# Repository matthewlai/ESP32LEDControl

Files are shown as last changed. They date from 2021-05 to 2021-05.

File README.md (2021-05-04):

# ESP32LEDControl

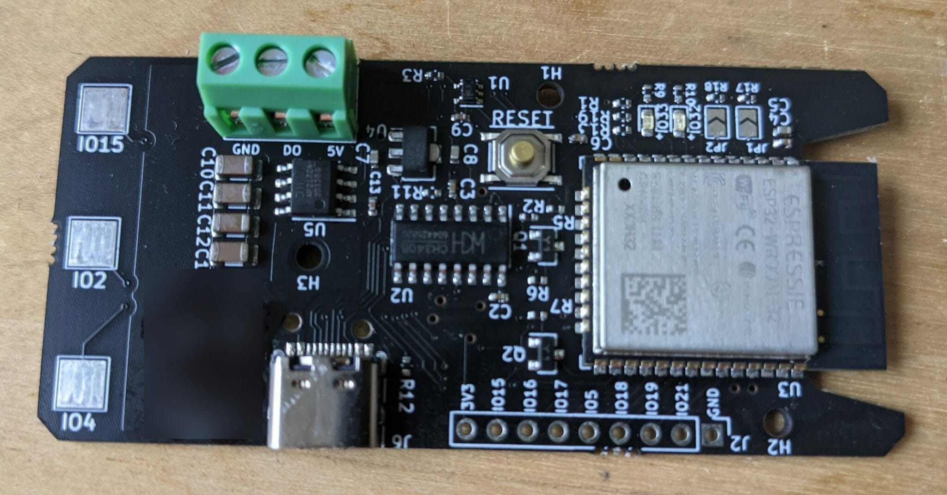
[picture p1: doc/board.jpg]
PCB photo


ESP32-based LED controller for WS2812B-compatible LEDs, powered by USB Type-C.

This is the hardware component of Fede Heinz's [Blinkenlights project](https://github.com/fheinz/Blinkenlights).

See [this blog post](https://dubiouscreations.com/2021/05/04/designing-an-esp32-based-rgb-matrix-driver-and-making-500-of-them/) for more details.

This hardware design is licensed under Attribution-ShareAlike 4.0 International (CC BY-SA 4.0) as published by the Creative Commons. You can find a copy of the license [here](https://creativecommons.org/licenses/by-sa/4.0/).

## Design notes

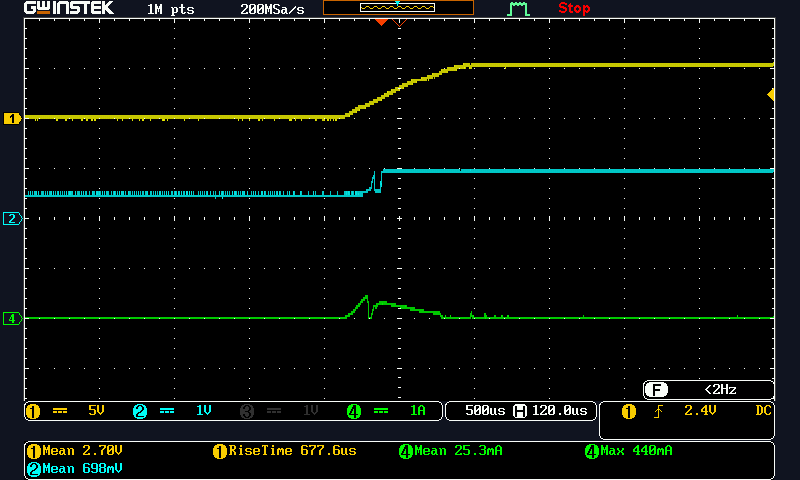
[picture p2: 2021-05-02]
hardware/esp32_led_controller/doc/rev4_hw_qual/plug_in.png

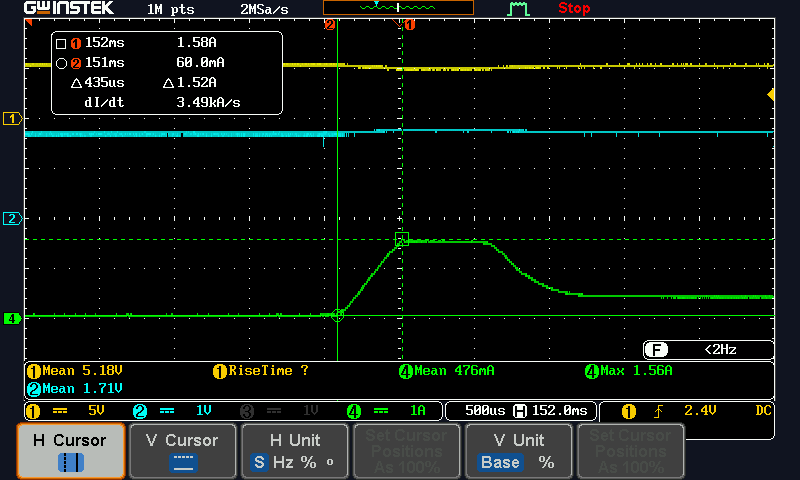
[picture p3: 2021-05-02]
hardware/esp32_led_controller/doc/rev4_hw_qual/usb_switch_on.png

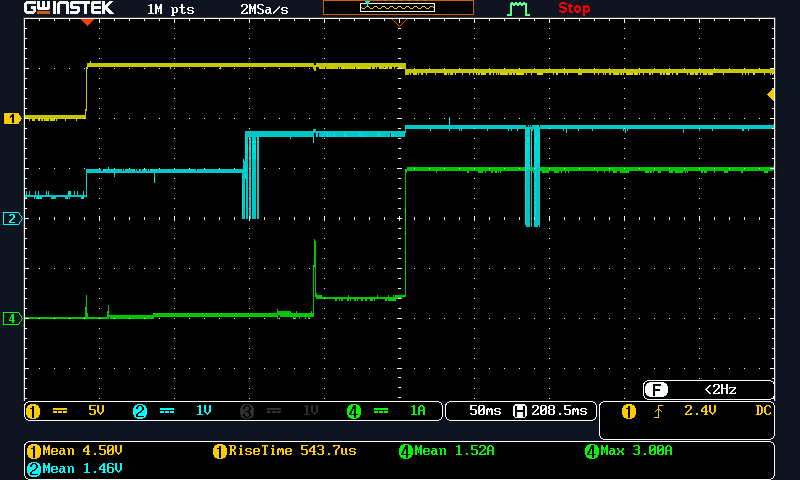
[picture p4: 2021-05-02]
hardware/esp32_led_controller/doc/rev4_hw_qual/led_on.png

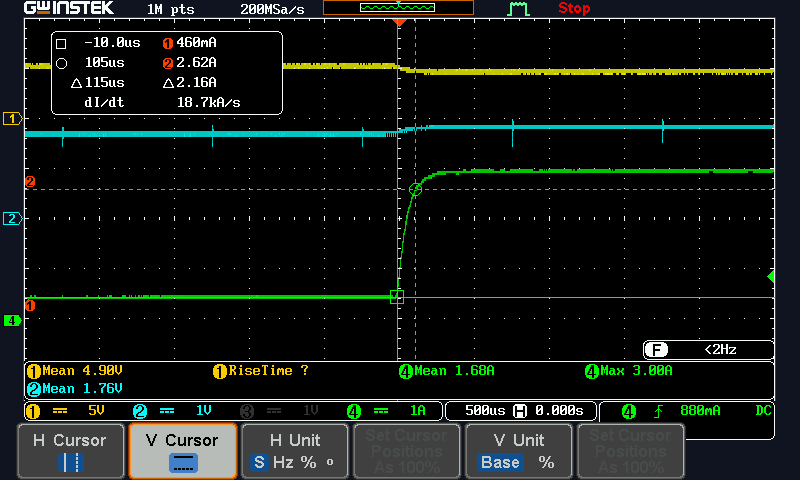
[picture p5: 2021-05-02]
hardware/esp32_led_controller/doc/rev4_hw_qual/led_on_current.png

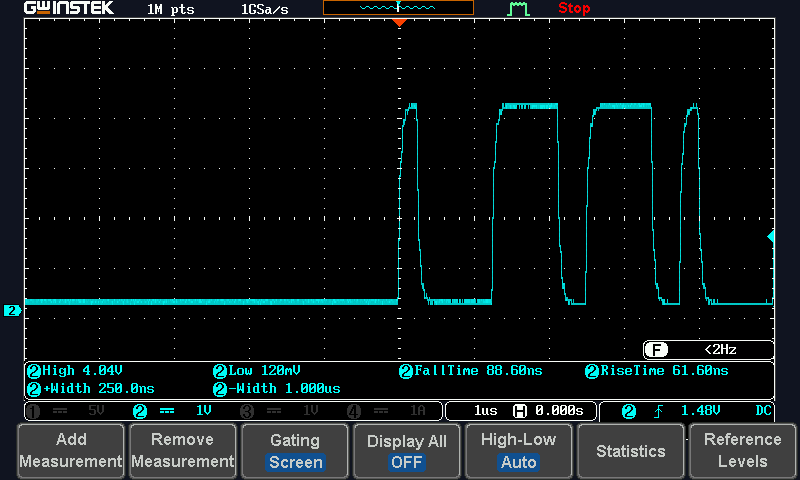
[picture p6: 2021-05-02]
hardware/esp32_led_controller/doc/rev4_hw_qual/dout_1.png

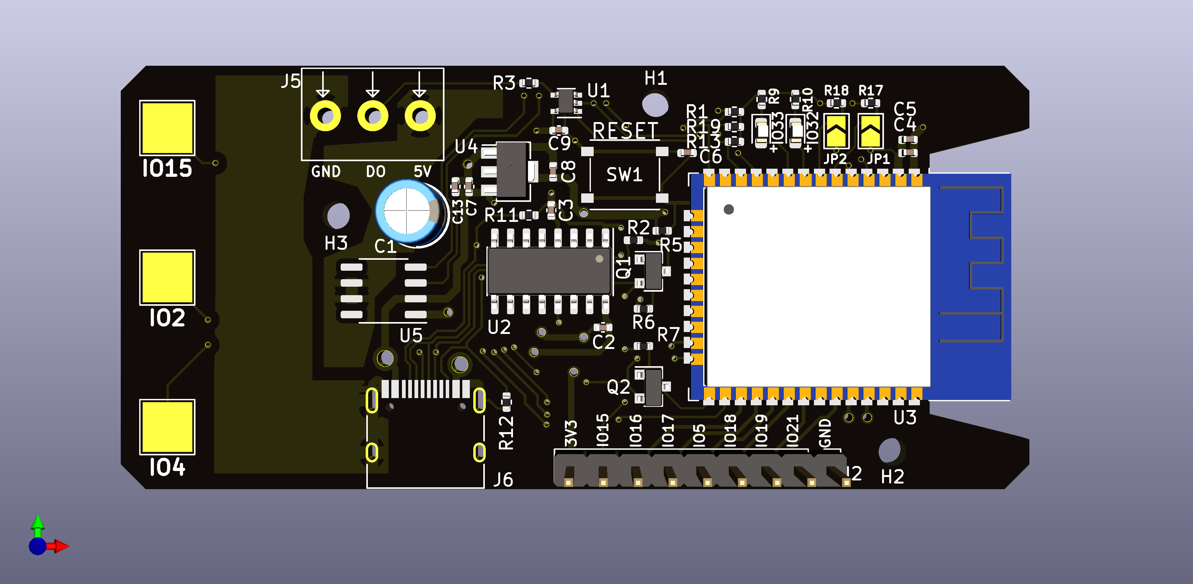
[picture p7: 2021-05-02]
hardware/esp32_led_controller/doc/esp32_led_controller.png

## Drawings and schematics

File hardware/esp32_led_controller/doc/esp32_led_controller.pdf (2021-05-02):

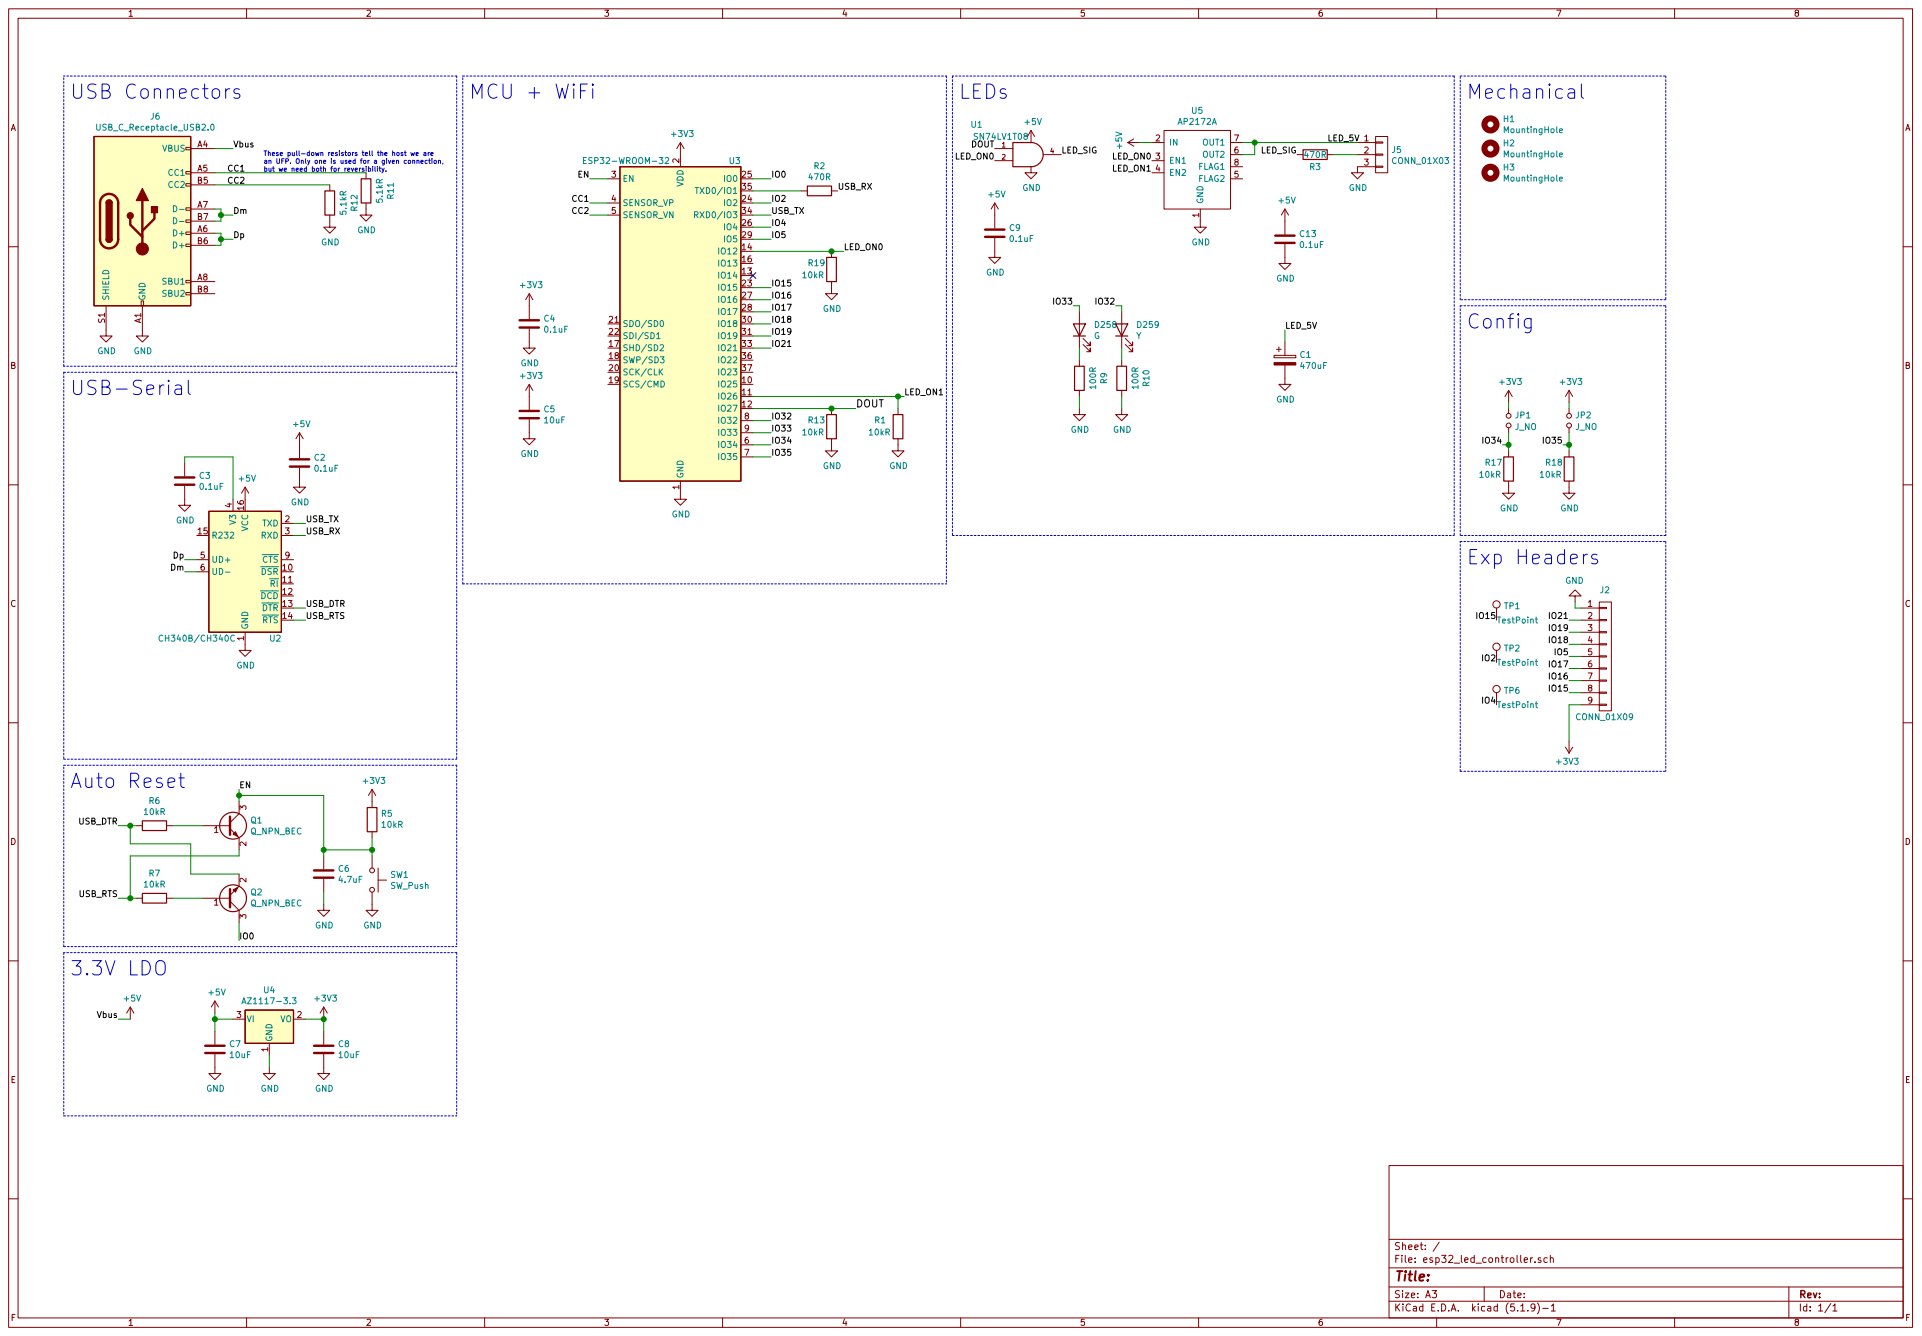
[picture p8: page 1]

These pull-down resistors tell the host we are

an UFP. Only one is used for a given connection, but we need both for reversibility. USB-Serial

2 SCK/CLK 20 SDO/SD0 21 SDI/SD1 22

4 UD+ 5 UD- 6 CTS 9 CH340B/CH340C U2 GND

1 DSR 10 RI 11 DCD 12 DTR 13 RTS 14 R232 15 VCC 16 TXD 2 RXD 3 V3

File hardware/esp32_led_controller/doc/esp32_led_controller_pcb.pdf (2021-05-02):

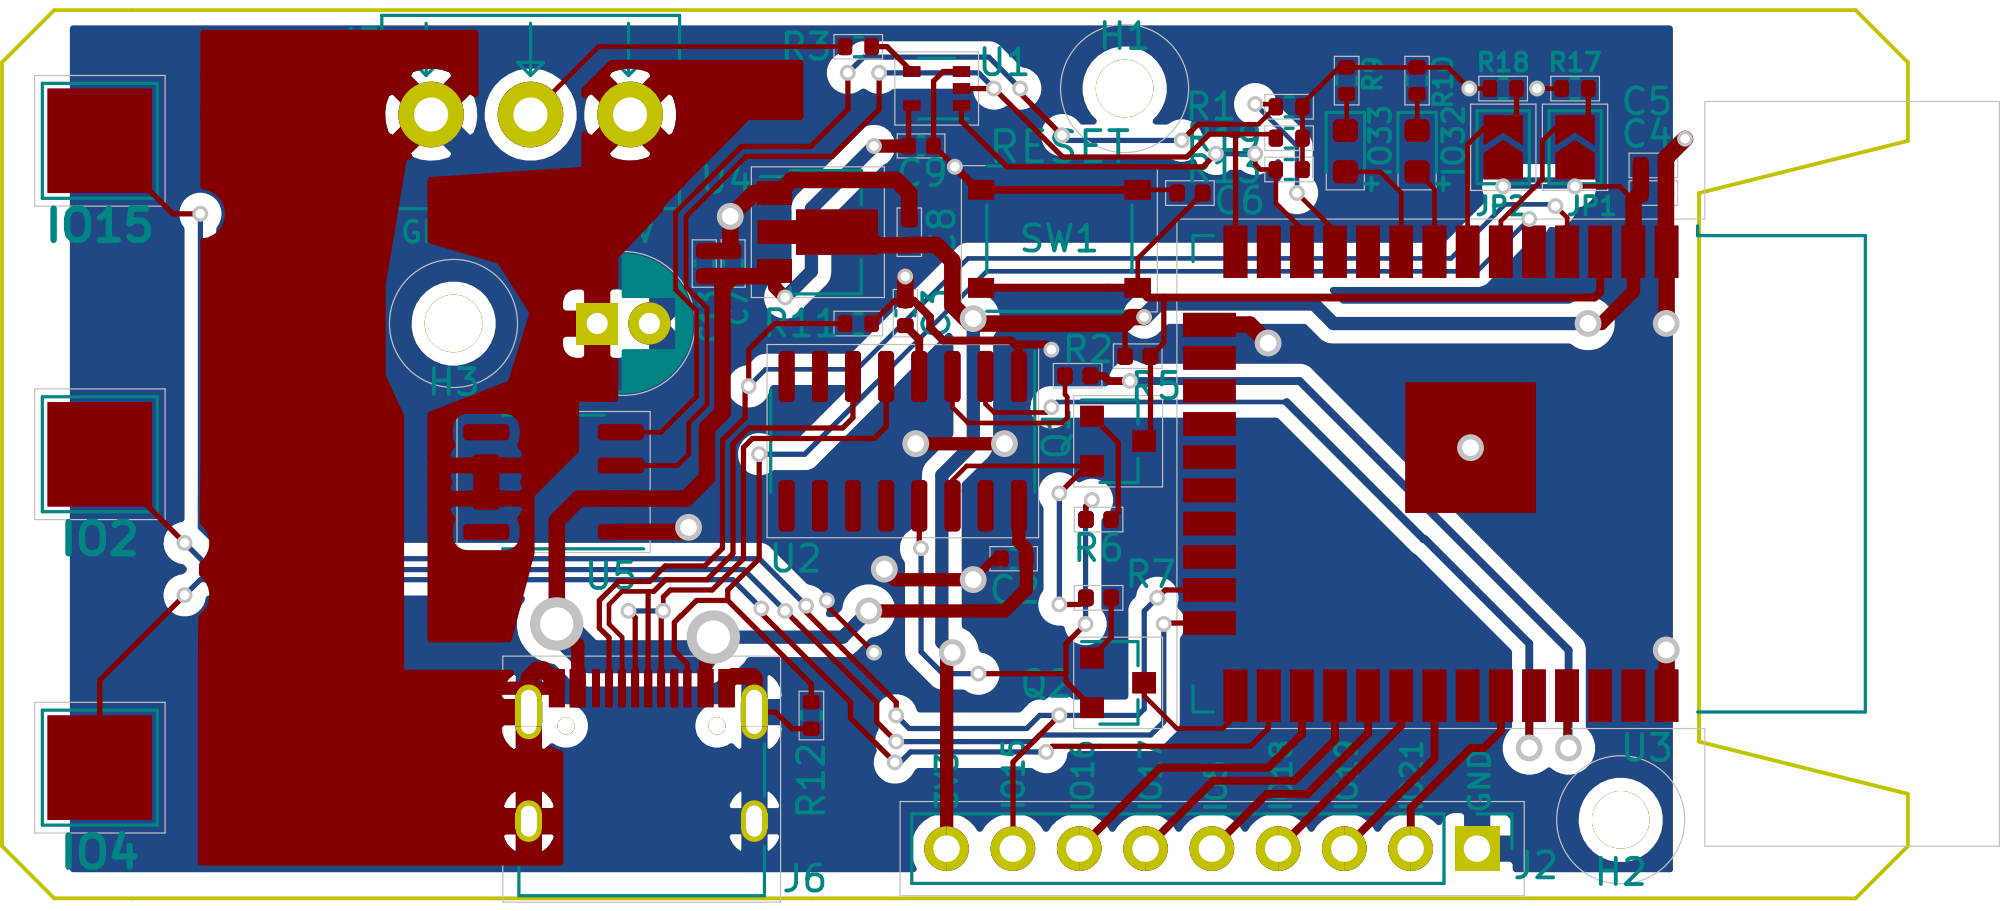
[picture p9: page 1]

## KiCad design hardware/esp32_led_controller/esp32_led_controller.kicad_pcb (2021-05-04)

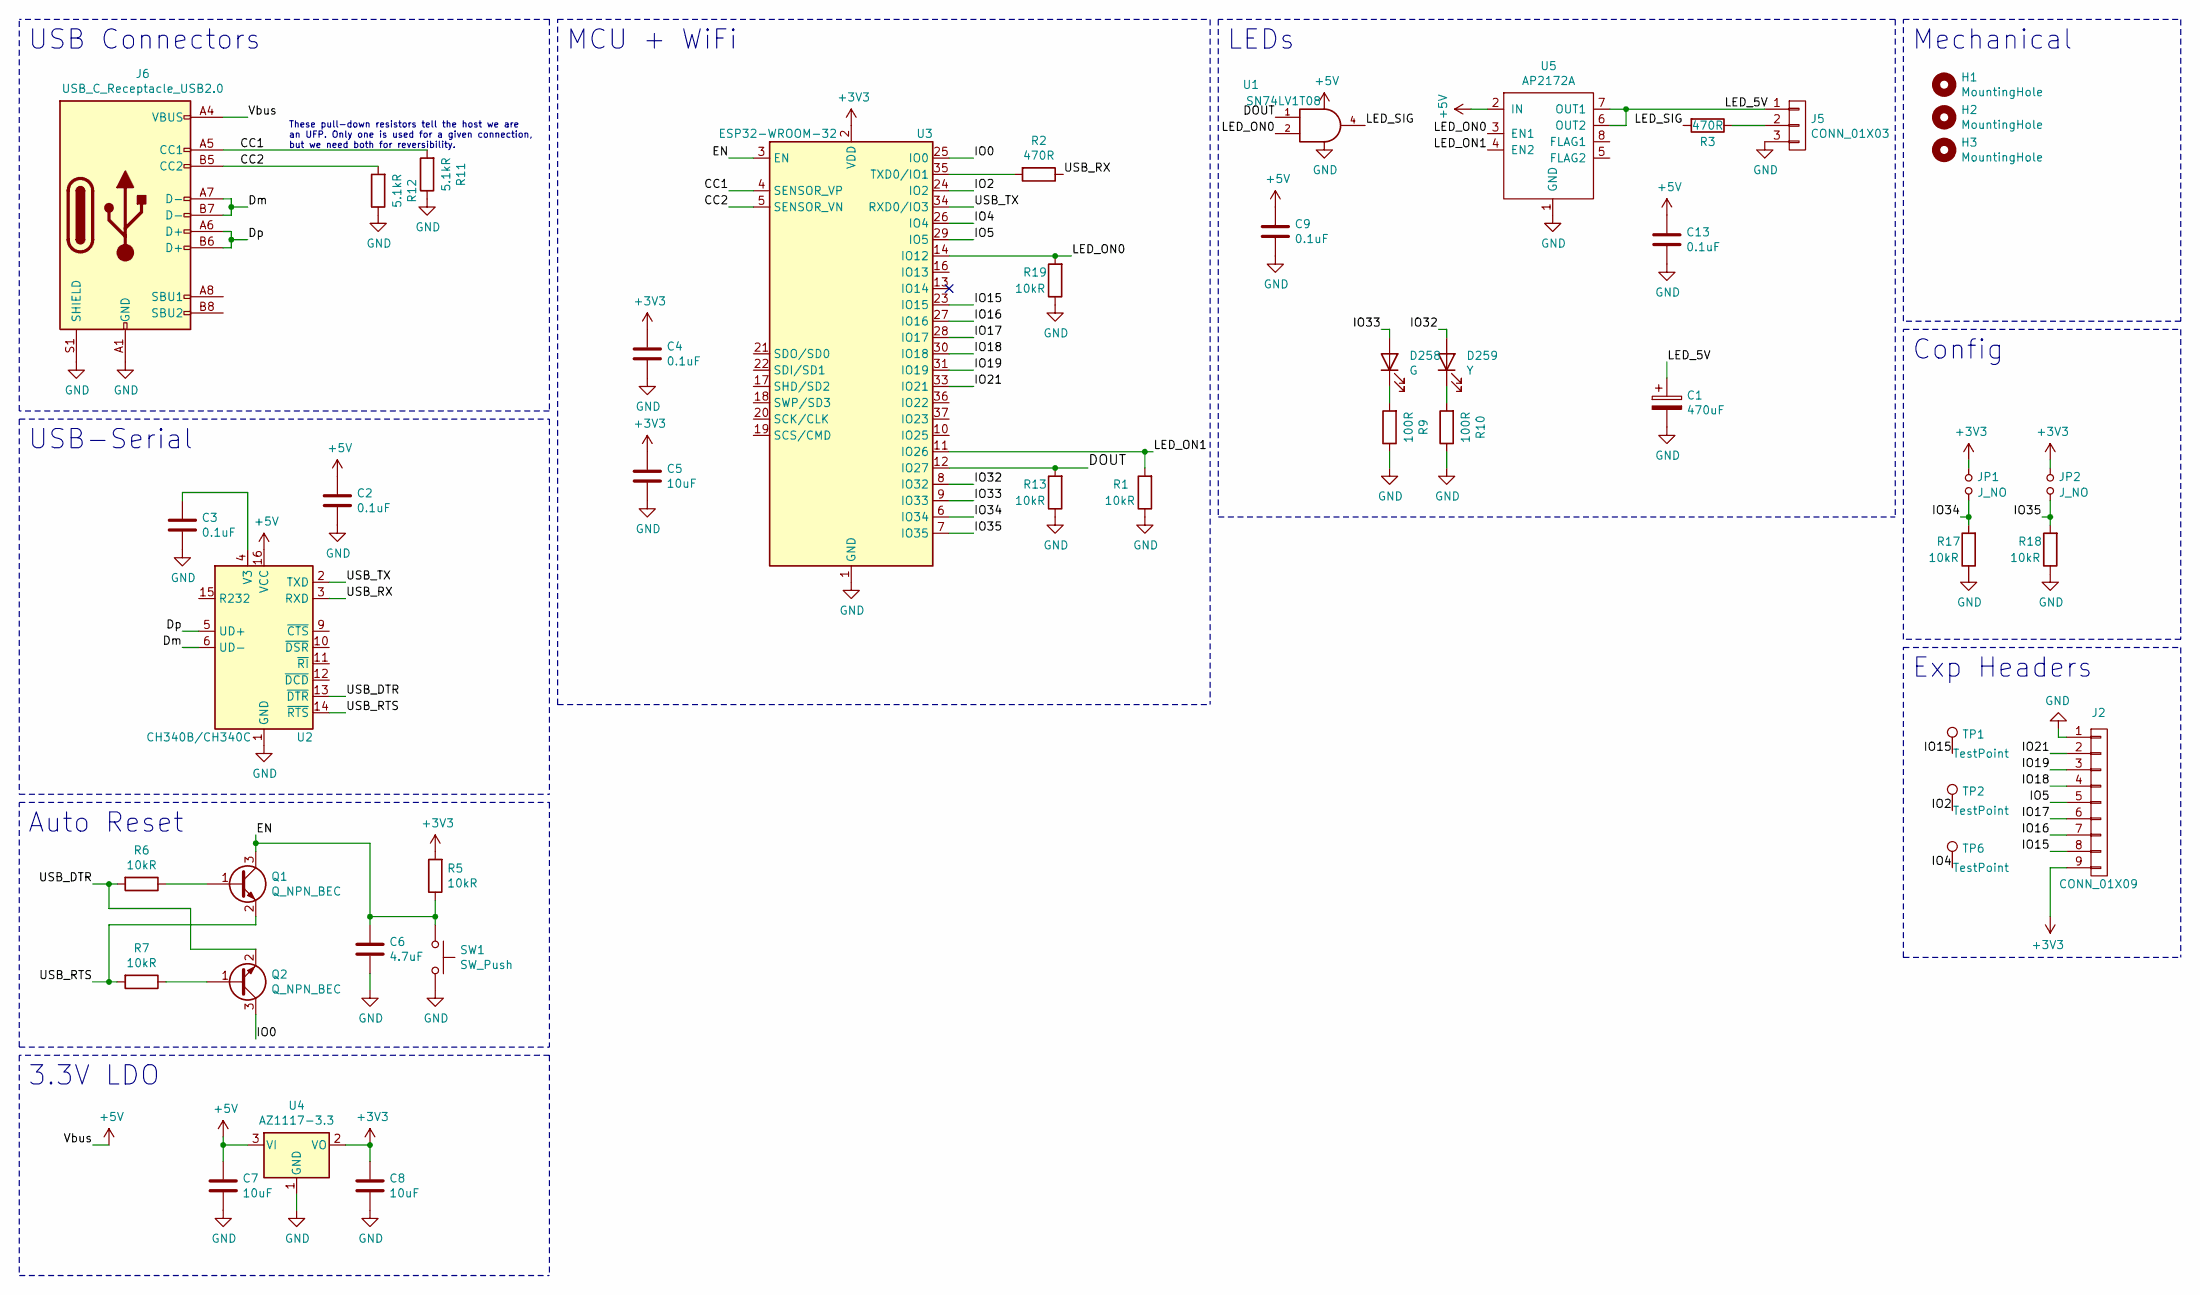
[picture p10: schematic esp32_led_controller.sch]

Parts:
C1: 470uF; CP_Radial_D5.0mm_P2.00mm; LCSC C112519
C2, C3, C4, C9, C13: 0.1uF; C_0402_1005Metric; LCSC C1525
C5, C7, C8: 10uF; C_0402_1005Metric; LCSC C15525
C6: 4.7uF; C_0402_1005Metric; LCSC C23733
D258: G; LED_0603_1608Metric; LCSC C72043
D259: Y; LED_0603_1608Metric; LCSC C72038
H1, H2, H3: MountingHole; MountingHole_2.2mm_M2
J2: CONN_01X09; PinHeader_1x09_P2.54mm_Vertical
J5: CONN_01X03; KF128L-3.81-3P; LCSC C474933
J6: USB_C_Receptacle_USB2.0; USB_C_Receptacle_HRO_TYPE-C-31-M-12; LCSC C165948
JP1, JP2: J_NO; SolderJumper-2_P1.3mm_Open_TrianglePad1.0x1.5mm
Q1, Q2: Q_NPN_BEC; SOT-23; LCSC C2150
R1, R5, R6, R7, R13, R17, R18, R19: 10kR; R_0402_1005Metric; LCSC C25744
R2, R3: 470R; R_0402_1005Metric; LCSC C25117
R9, R10: 100R; R_0402_1005Metric; LCSC C25076
R11, R12: 5.1kR; R_0402_1005Metric; LCSC C25905
SW1: SW_Push; SW_Push_1P1T_NO_5.1x5.1mm; LCSC C318887
TP1, TP2, TP6: TestPoint; TestPoint_Pad_4.0x4.0mm
U1: SN74LV1T08; SOT-353_SC-70-5; LCSC C130199
U2: CH340B/CH340C; SOIC-16_3.9x9.9mm_P1.27mm; LCSC C81010
U3: ESP32-WROOM-32; LCSC C82899
U4: AZ1117-3.3; SOT-89-3; LCSC C108493
U5: AP2172A; SO-8_3.9x4.9mm_P1.27mm; LCSC C151327

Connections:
+3V3: C4.1, C5.1, C8.1, J2.9, JP1.1, JP2.1, R5.2, U3.2 (VDD), U4.2 (VO)
+5V: C2.1, C7.1, C9.1, C13.1, J6.A4 (VBUS), J6.A9 (VBUS), J6.B4 (VBUS), J6.B9 (VBUS), U1.5 (VCC), U2.16 (VCC), U4.3 (VI), U5.2 (IN)
/CC1: J6.A5 (CC1), R11.2, U3.4 (SENSOR_VP)
/CC2: J6.B5 (CC2), R12.2, U3.5 (SENSOR_VN)
/DOUT: R13.2, U1.1, U3.12 (IO27)
/Dm: J6.A7 (D-), J6.B7 (D-), U2.6 (UD-)
/Dp: J6.A6 (D+), J6.B6 (D+), U2.5 (UD+)
/EN: C6.1, Q1.3 (C), R5.1, SW1.1, U3.3 (EN)
/IO0: Q2.3 (C), U3.25 (IO0)
/IO2: TP2.1, U3.24 (IO2)
/IO4: TP6.1, U3.26 (IO4)
/IO5: J2.5, U3.29 (IO5)
/IO15: J2.8, TP1.1, U3.23 (IO15)
/IO16: J2.7, U3.27 (IO16)
/IO17: J2.6, U3.28 (IO17)
/IO18: J2.4, U3.30 (IO18)
/IO19: J2.3, U3.31 (IO19)
/IO21: J2.2, U3.33 (IO21)
/IO32: D259.2 (A), U3.8 (IO32)
/IO33: D258.2 (A), U3.9 (IO33)
/IO34: JP1.2, R17.2, U3.6 (IO34)
/IO35: JP2.2, R18.2, U3.7 (IO35)
/LED_5V: C1.1, J5.1, U5.6 (OUT2), U5.7 (OUT1)
/LED_ON0: R19.2, U1.2, U3.14 (IO12), U5.3 (EN1)
/LED_ON1: R1.2, U3.11 (IO26), U5.4 (EN2)
/LED_SIG: R3.2, U1.4
/USB_DTR: Q2.2 (E), R6.2, U2.13 (~DTR)
/USB_RTS: Q1.2 (E), R7.2, U2.14 (~RTS)
/USB_RX: R2.1, U2.3 (RXD)
/USB_TX: U2.2 (TXD), U3.34 (RXD0/IO3)
GND: C1.2, C2.2, C3.2, C4.2, C5.2, C6.2, C7.2, C8.2, C9.2, C13.2, J2.1, J5.3, J6.A1 (GND), J6.A12 (GND), J6.B1 (GND), J6.B12 (GND), J6.S1 (SHIELD), R1.1, R9.1, R10.1, R11.1, R12.1, R13.1, R17.1, R18.1, R19.1, SW1.2, U1.3 (GND), U2.1 (GND), U3.1 (GND), U3.15 (GND), U3.38 (GND), U3.39 (GND), U4.1 (GND), U5.1 (GND)
unnamed: C3.1, U2.4 (V3)
unnamed: D258.1 (K), R9.2
unnamed: D259.1 (K), R10.2
unnamed: J5.2, R3.1
unnamed: Q1.1 (B), R6.1
unnamed: Q2.1 (B), R7.1
unnamed: R2.2, U3.35 (TXD0/IO1)

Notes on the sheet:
USB-Serial
Auto Reset
MCU + WiFi
3.3V LDO
Exp Headers
LEDs
Mechanical
USB Connectors
These pull-down resistors tell the host we are an UFP. Only one is used for a given connection, but we need both for reversibility.
Config

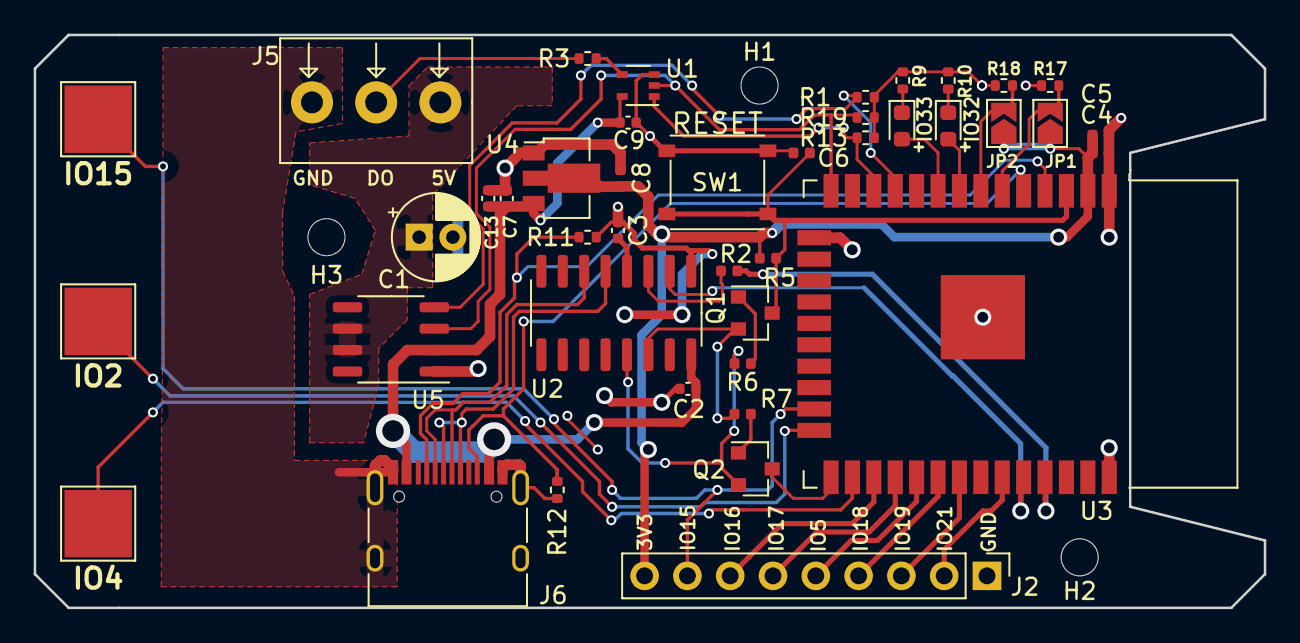
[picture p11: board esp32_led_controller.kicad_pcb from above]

Board: 4 copper layers, 73.0 x 34.0 mm, 45 parts (0 on the bottom side), 38 nets.

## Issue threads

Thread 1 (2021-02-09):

ESP32 Code for this project

madnat, 2021-02-09:
Hi there - nice project, thanks for sharing the very helpful design information.  I couldn't spot any code for controlling the MOSFET/LED from the ESP32, did you chare it - could that be added to the respository?

Thanks again

matthewlai, 2021-02-09:
Hi @madnat, thanks! I'm surprised you found this - we haven't advertised it anywhere yet.

This is still in heavy development, so although we think the hardware design is ready, it hasn't been produced and verified yet. I would recommend waiting till we have verified it before using this!

The firmware doesn't exist yet :). Our intention is to put it on here when we have written it.

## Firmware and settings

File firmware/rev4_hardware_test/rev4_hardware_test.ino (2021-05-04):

#include <FastLED.h>
 
constexpr int kOnboardLed0Pin = 32;
constexpr int kOnboardLed1Pin = 33;
 
// These are enable lines for the matrix power switch.
// If only Pin0 is high, the matrix is current-limited to 1.5A.
// If both are high, the matrix is current-limited to 3A.
// The switch resistance is lower with both enabled, so we always
// enable Pin0 first to charge up the capacitances (since we may
// only be allowed 1.5A), then enable Pin1 even if we only have
// 1.5A available to improve switch efficiency, and apply current
// limit in firmware instead (not setting LEDs too bright).
constexpr int kLedMatrixPowerPin0 = 12;
constexpr int kLedMatrixPowerPin1 = 26;
 
constexpr int kLedMatrixDataPin = 27;
constexpr int kUsbCc1Pin = 36;
constexpr int kUsbCc2Pin = 39;
constexpr int kTouch0Pin = 15;
constexpr int kTouch1Pin = 2;
constexpr int kTouch2Pin = 4;
 
template <int kIo>
class TouchButtonReader {
 public:
  TouchButtonReader()
      : filtered_value(static_cast<float>(touchRead(kIo))) {}
  
  void Update() {
    filtered_value *= kFilterStrength;
    filtered_value += (1.0f - kFilterStrength) * touchRead(kIo);
  }
 
  int Value() { return static_cast<int>(filtered_value); }
 
 private:
  static constexpr float kFilterStrength = 0.7f;
  float filtered_value;
};
 
enum class UsbCurrentAvailable {
  // USB-C host and we can draw 3A.
  k3A,
 
  // USB-C host and we can draw 1.5A.
  k1_5A,
 
  // We have either a USB-C host with no high current
  // capability or a legacy host / 1.5A (BCS) power supply. We do
  // not have the hardware to tell them apart, so we
  // can't make any assumptions on current available
  // beyond 100mA (though most hosts will be fine with 500mA).
  kUsbStd,
};
 
float AnalogReadV(int pin) {
  // By default we have 11db (1/3.6) attenuation with 1.1V reference,
  // so full scale voltage range is 1.1*3.6 = 3.96. In reality it's
  // clamped to Vdd (3.3V) so we will never get a reading above that,
  // but we need to the calculations using 3.96.
  return analogRead(pin) * 3.96f / 4096;
}
 
UsbCurrentAvailable DetermineMaxCurrent() {
  // This function implements USB-C current advertisement detection.
  // Universal Serial Bus Type-C Cable and Connector Specification
  // Depending on cable orientation, either CC1 or CC2 will be >0V,
  // and that tells us how much current we can draw.
  // Voltage thresholds from Table 4-36:
  // >0.2V = connected, >0.66V = 1.5A, >1.23V = 3A.
  float cc1 = AnalogReadV(kUsbCc1Pin);
  float cc2 = AnalogReadV(kUsbCc2Pin);
  float cc = max(cc1, cc2);
  if (cc > 1.23f) {
    return UsbCurrentAvailable::k3A;
  } else if (cc > 0.66f) {
    return UsbCurrentAvailable::k1_5A;
  } else {
    return UsbCurrentAvailable::kUsbStd;
  }
}
 
void EnableLEDPower() {
  // Make sure data pin is low so we don't latch up the LEDs.
  digitalWrite(kLedMatrixDataPin, LOW);
 
  // Enable 1.5A current to charge up the capacitances.
  digitalWrite(kLedMatrixPowerPin0, HIGH);
 
  delay(50 /* milliseconds */);
 
  // Enable the second 1.5A switch to reduce switch resistance
  // even if we only have 1.5A total, because we can limit it in
  // firmware instead.
  digitalWrite(kLedMatrixPowerPin1, HIGH);
}
 
void DisableLEDPower() {
  digitalWrite(kLedMatrixDataPin, LOW);
  digitalWrite(kLedMatrixPowerPin1, LOW);
  digitalWrite(kLedMatrixPowerPin0, LOW);
}
 
constexpr int kMatrixSize = 256;
constexpr float kMatrixMaxCurrent = kMatrixSize * 0.06f; // WS2812B: 60mA/LED
constexpr float kMaxIdleCurrent = 0.5f; // Matrix + ESP32 idle
CRGB leds[kMatrixSize];
 
void setup() {
  Serial.begin(115200);
  pinMode(kOnboardLed0Pin, OUTPUT);
  pinMode(kOnboardLed1Pin, OUTPUT);
  pinMode(kLedMatrixDataPin, OUTPUT);
  pinMode(kLedMatrixPowerPin0, OUTPUT);
  pinMode(kLedMatrixPowerPin1, OUTPUT);
  pinMode(kTouch0Pin, INPUT);
  pinMode(kTouch1Pin, INPUT);
  pinMode(kTouch2Pin, INPUT);
  FastLED.addLeds<NEOPIXEL, kLedMatrixDataPin>(leds, kMatrixSize);
}
 
void loop() {
  static UsbCurrentAvailable current_available =
      UsbCurrentAvailable::kUsbStd;
  UsbCurrentAvailable current_advertisement = DetermineMaxCurrent();
  if (current_available != current_advertisement) {
    // Wait 15ms and read again to make sure it's stable (not a PD message). See comment below
    // for more details.
    delay(15);
    if (DetermineMaxCurrent() == current_advertisement) {
      switch (current_advertisement) {
        case UsbCurrentAvailable::k3A:
          digitalWrite(kOnboardLed0Pin, HIGH);
          digitalWrite(kOnboardLed1Pin, HIGH);
          FastLED.setBrightness(255 * (3.0f - kMaxIdleCurrent) / kMatrixMaxCurrent);
          EnableLEDPower();
          break;
        case UsbCurrentAvailable::k1_5A:
          digitalWrite(kOnboardLed0Pin, LOW);
          digitalWrite(kOnboardLed1Pin, HIGH);
          FastLED.setBrightness(255 * (1.5f - kMaxIdleCurrent) / kMatrixMaxCurrent);
          EnableLEDPower();
          break;
        default:
          digitalWrite(kOnboardLed0Pin, LOW);
          digitalWrite(kOnboardLed1Pin, LOW);
          DisableLEDPower();
      }
      current_available = current_advertisement;
    }
  }
 
  static CRGB colour = CRGB::White;
 
  static TouchButtonReader<kTouch0Pin> touch0;
  static TouchButtonReader<kTouch1Pin> touch1;
  static TouchButtonReader<kTouch2Pin> touch2;
 
  touch0.Update();
  touch1.Update();
  touch2.Update();
 
  if (touch0.Value() < 20) {
    colour = CRGB::White;
  } else if (touch1.Value() < 20) {
    colour = CRGB::Blue;
  } else if (touch2.Value() < 20) {
    colour = CRGB::Black;
  }
 
  Serial.printf("%d %d %d\n", touch0.Value(), touch1.Value(), touch2.Value());
 
  FastLED.showColor(colour);
 
  // USB-C spec says the host can change the advertised current limit at any time,
  // and we have tSinkAdj(max) (60ms) to comply.
  // When we detect a CC value change, we also have to wait tRpValueChange(min) (10ms)
  // to make sure this is not a PD message (which cause, for our purposes, noise on the
  // CC line).
  // So we implement that by having the loop run at 30ms, and if we see a CC change,
  // we sample again in 15ms to make sure the value is stable, satisfying both timing
  // requirements.
  delay(30);
}

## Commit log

2021-02-07 Finished design with integrated LED matrix
    [esp32_led_controller.kicad_pcb, esp32_led_controller.sch, led_row.sch]
2021-02-07 Directory move
    [esp32_led_controller.kicad_pcb, esp32_led_controller.sch, led_row.sch]
2021-02-09 Improved silkscreen and added test points
    [esp32_led_controller.kicad_pcb, esp32_led_controller.sch, led_row.sch]
2021-02-09 Added configuration jumpers
    [esp32_led_controller.kicad_pcb, esp32_led_controller.sch]
2021-02-09 Updated BOM
    [esp32_led_controller.kicad_pcb]
2021-02-09 Added missing annotations
    [esp32_led_controller.sch]
2021-05-02 Added scope shots for rev4 boards
2021-05-02 Added rev4 hardware design
    [esp32_led_controller.kicad_pcb, esp32_led_controller.sch]
2021-05-02 Added panelization instructions and results
    [panel.kicad_pcb]
2021-05-04 Updated schematics aesthetics, and added board photo
    [esp32_led_controller.kicad_pcb, esp32_led_controller.sch]
2021-05-04 Removed panelisation outputs
    [panel.kicad_pcb]
